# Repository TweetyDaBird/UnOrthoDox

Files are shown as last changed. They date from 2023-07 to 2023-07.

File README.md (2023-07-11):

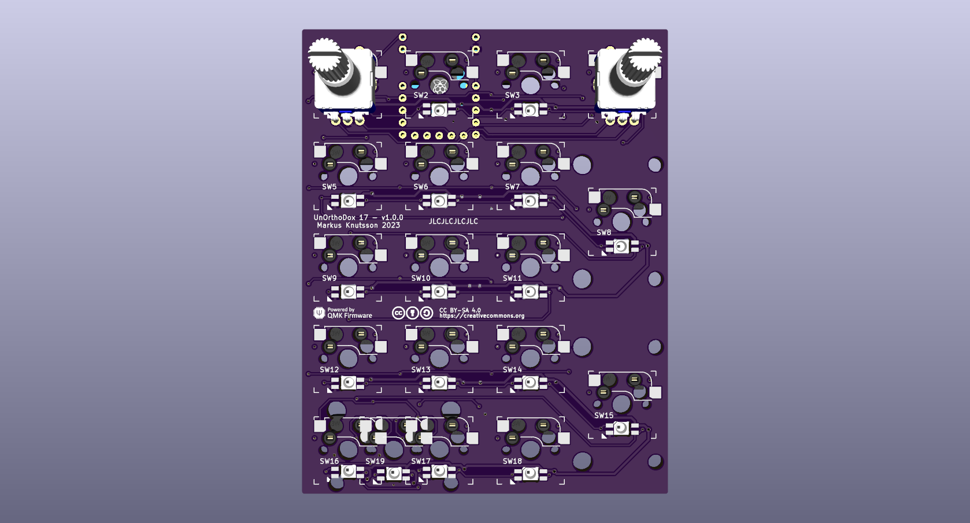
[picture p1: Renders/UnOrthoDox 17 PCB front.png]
Render UnOrthoDox 17
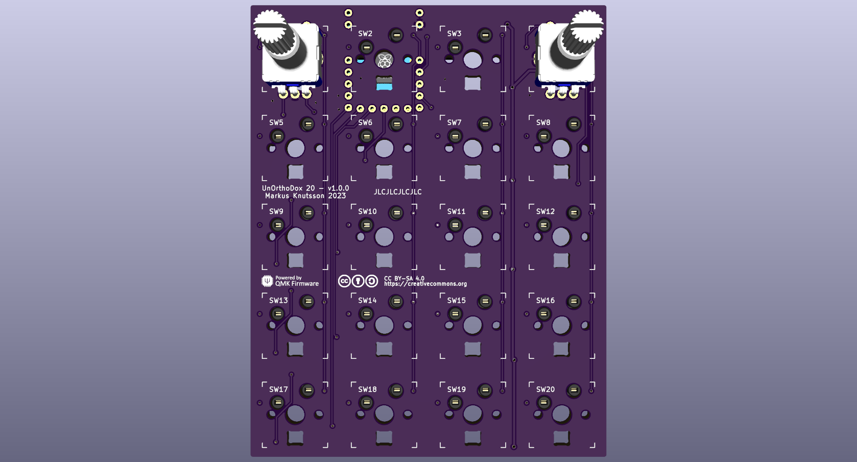
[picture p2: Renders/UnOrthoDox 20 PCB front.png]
Render UnOrthoDoc 20
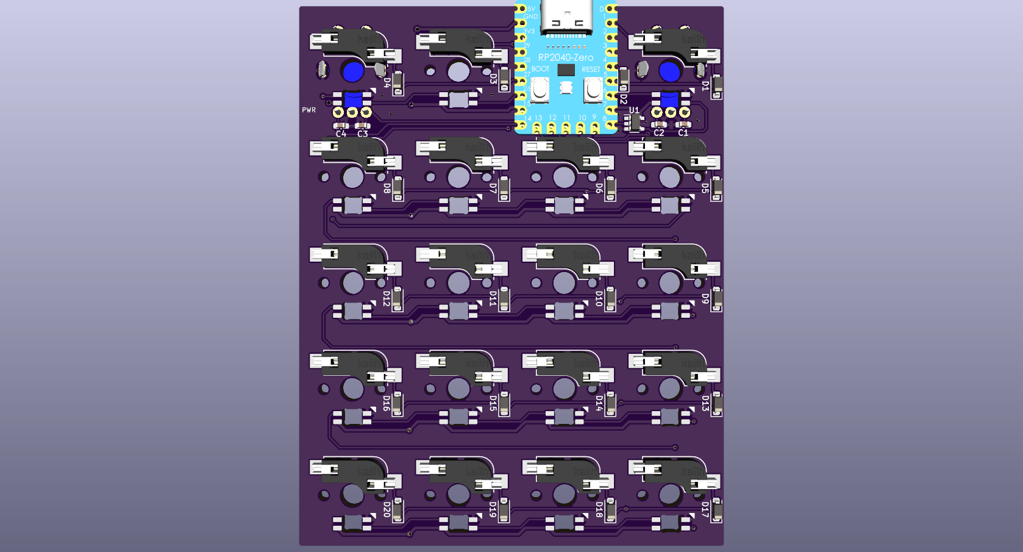
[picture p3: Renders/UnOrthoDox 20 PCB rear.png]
Render UnOrthoDoc Rear
|  |  | |
| --- | --- | --- |
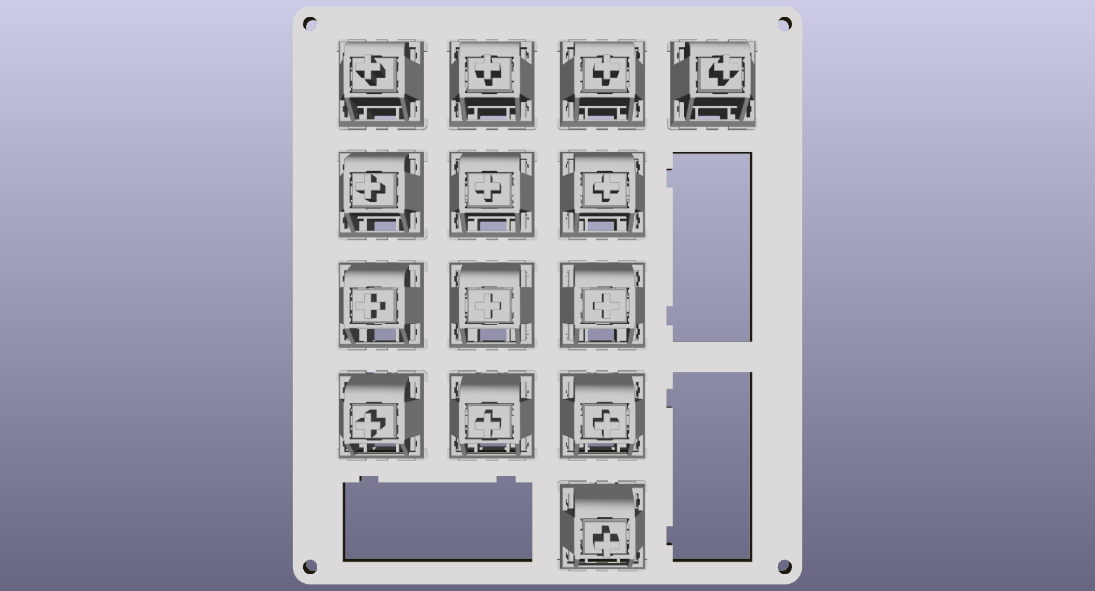
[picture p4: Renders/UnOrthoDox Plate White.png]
Render UnOrthoDox Front Plate
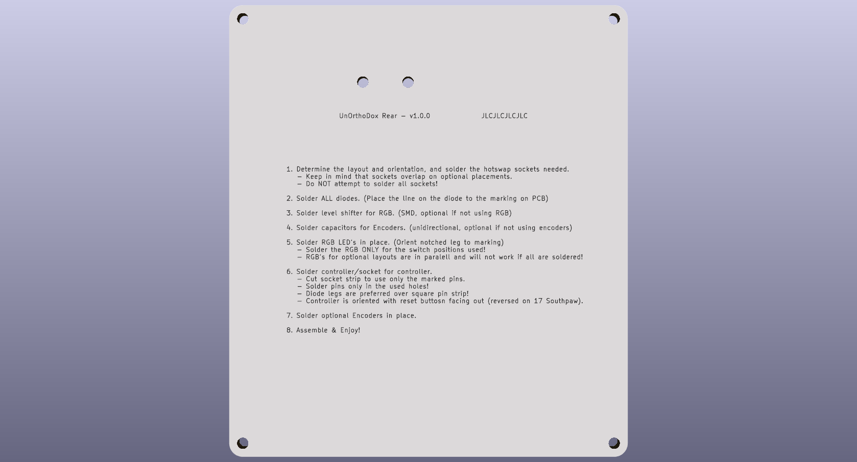
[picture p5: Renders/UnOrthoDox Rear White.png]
Render UnOrthoDox Rear Plate
| | |

# UnOrthoDox
A 'simple' and low cost hot-swap Numpad (available in 17-18 or 20 key versions) with support for dual encoders, and using a low cost but powerfull controller (RP2040-Zero). The design is dual sided, so flipping it over and building it as a 'SouthPaw' configuration is outright easy. A single plate/case design with cut-outs for all key configurations available in Black or White makes it easy to build a complete Numpad that fit's in well witha 60% keyboard in size and looks. The same plates/components fit both the 20-key PCB variant and the PCB-variant for a 17-18 key classic numpad layout. 

The name comes from the slightly unortodox placement of the controller straddling the hot-swap socket, with not all pins soldered, and the fact that it can be built as a 20-key ortholinear macro pad.

 - Full Sandwich Case design
 - Low cost/Simple to build
 - Powerful and Flexible MCU
 - Compatible with QMK/Vial and ZMK firmware
 - Reversible for SouthPaw's
 - Dual Rotary Encoders
 - Per-Key RGB
 - Build instructions are printed on the backplate for an easy build.

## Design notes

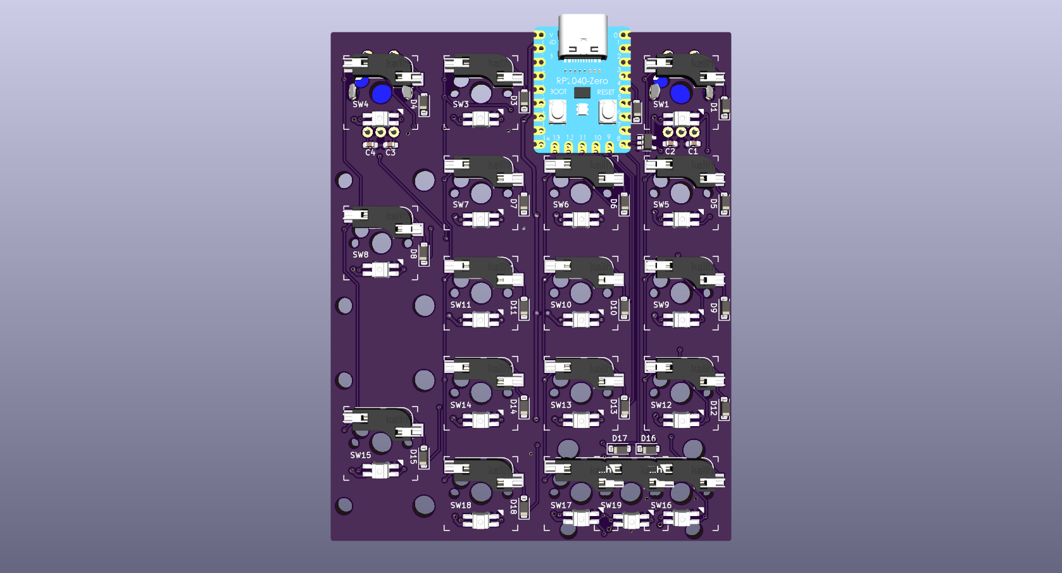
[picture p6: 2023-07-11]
Renders/UnOrthoDox 17 PCB rear.png

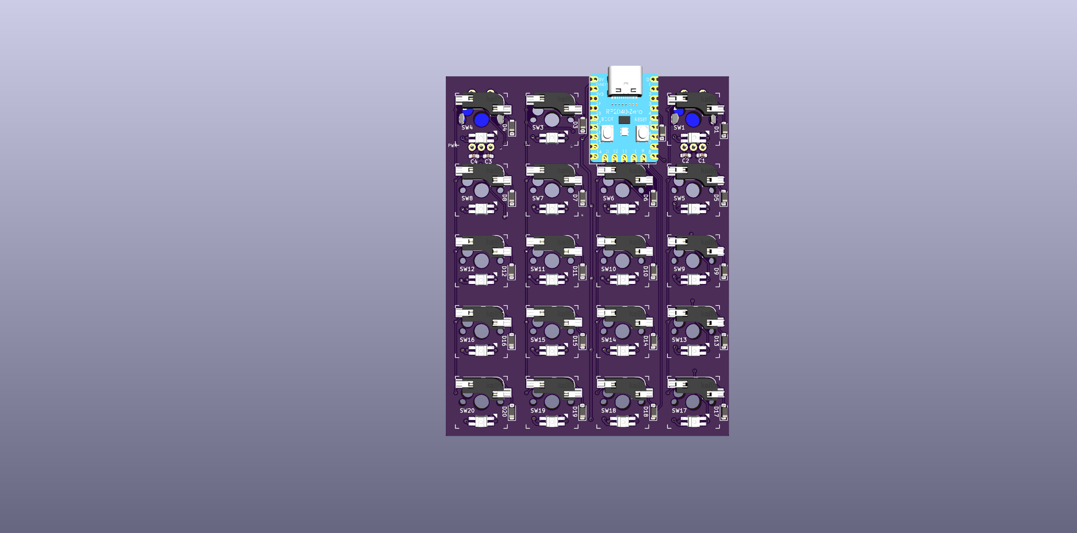
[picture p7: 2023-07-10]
UnOrthoDox 20 PCB/UnOrthoDox 20 PCB.png

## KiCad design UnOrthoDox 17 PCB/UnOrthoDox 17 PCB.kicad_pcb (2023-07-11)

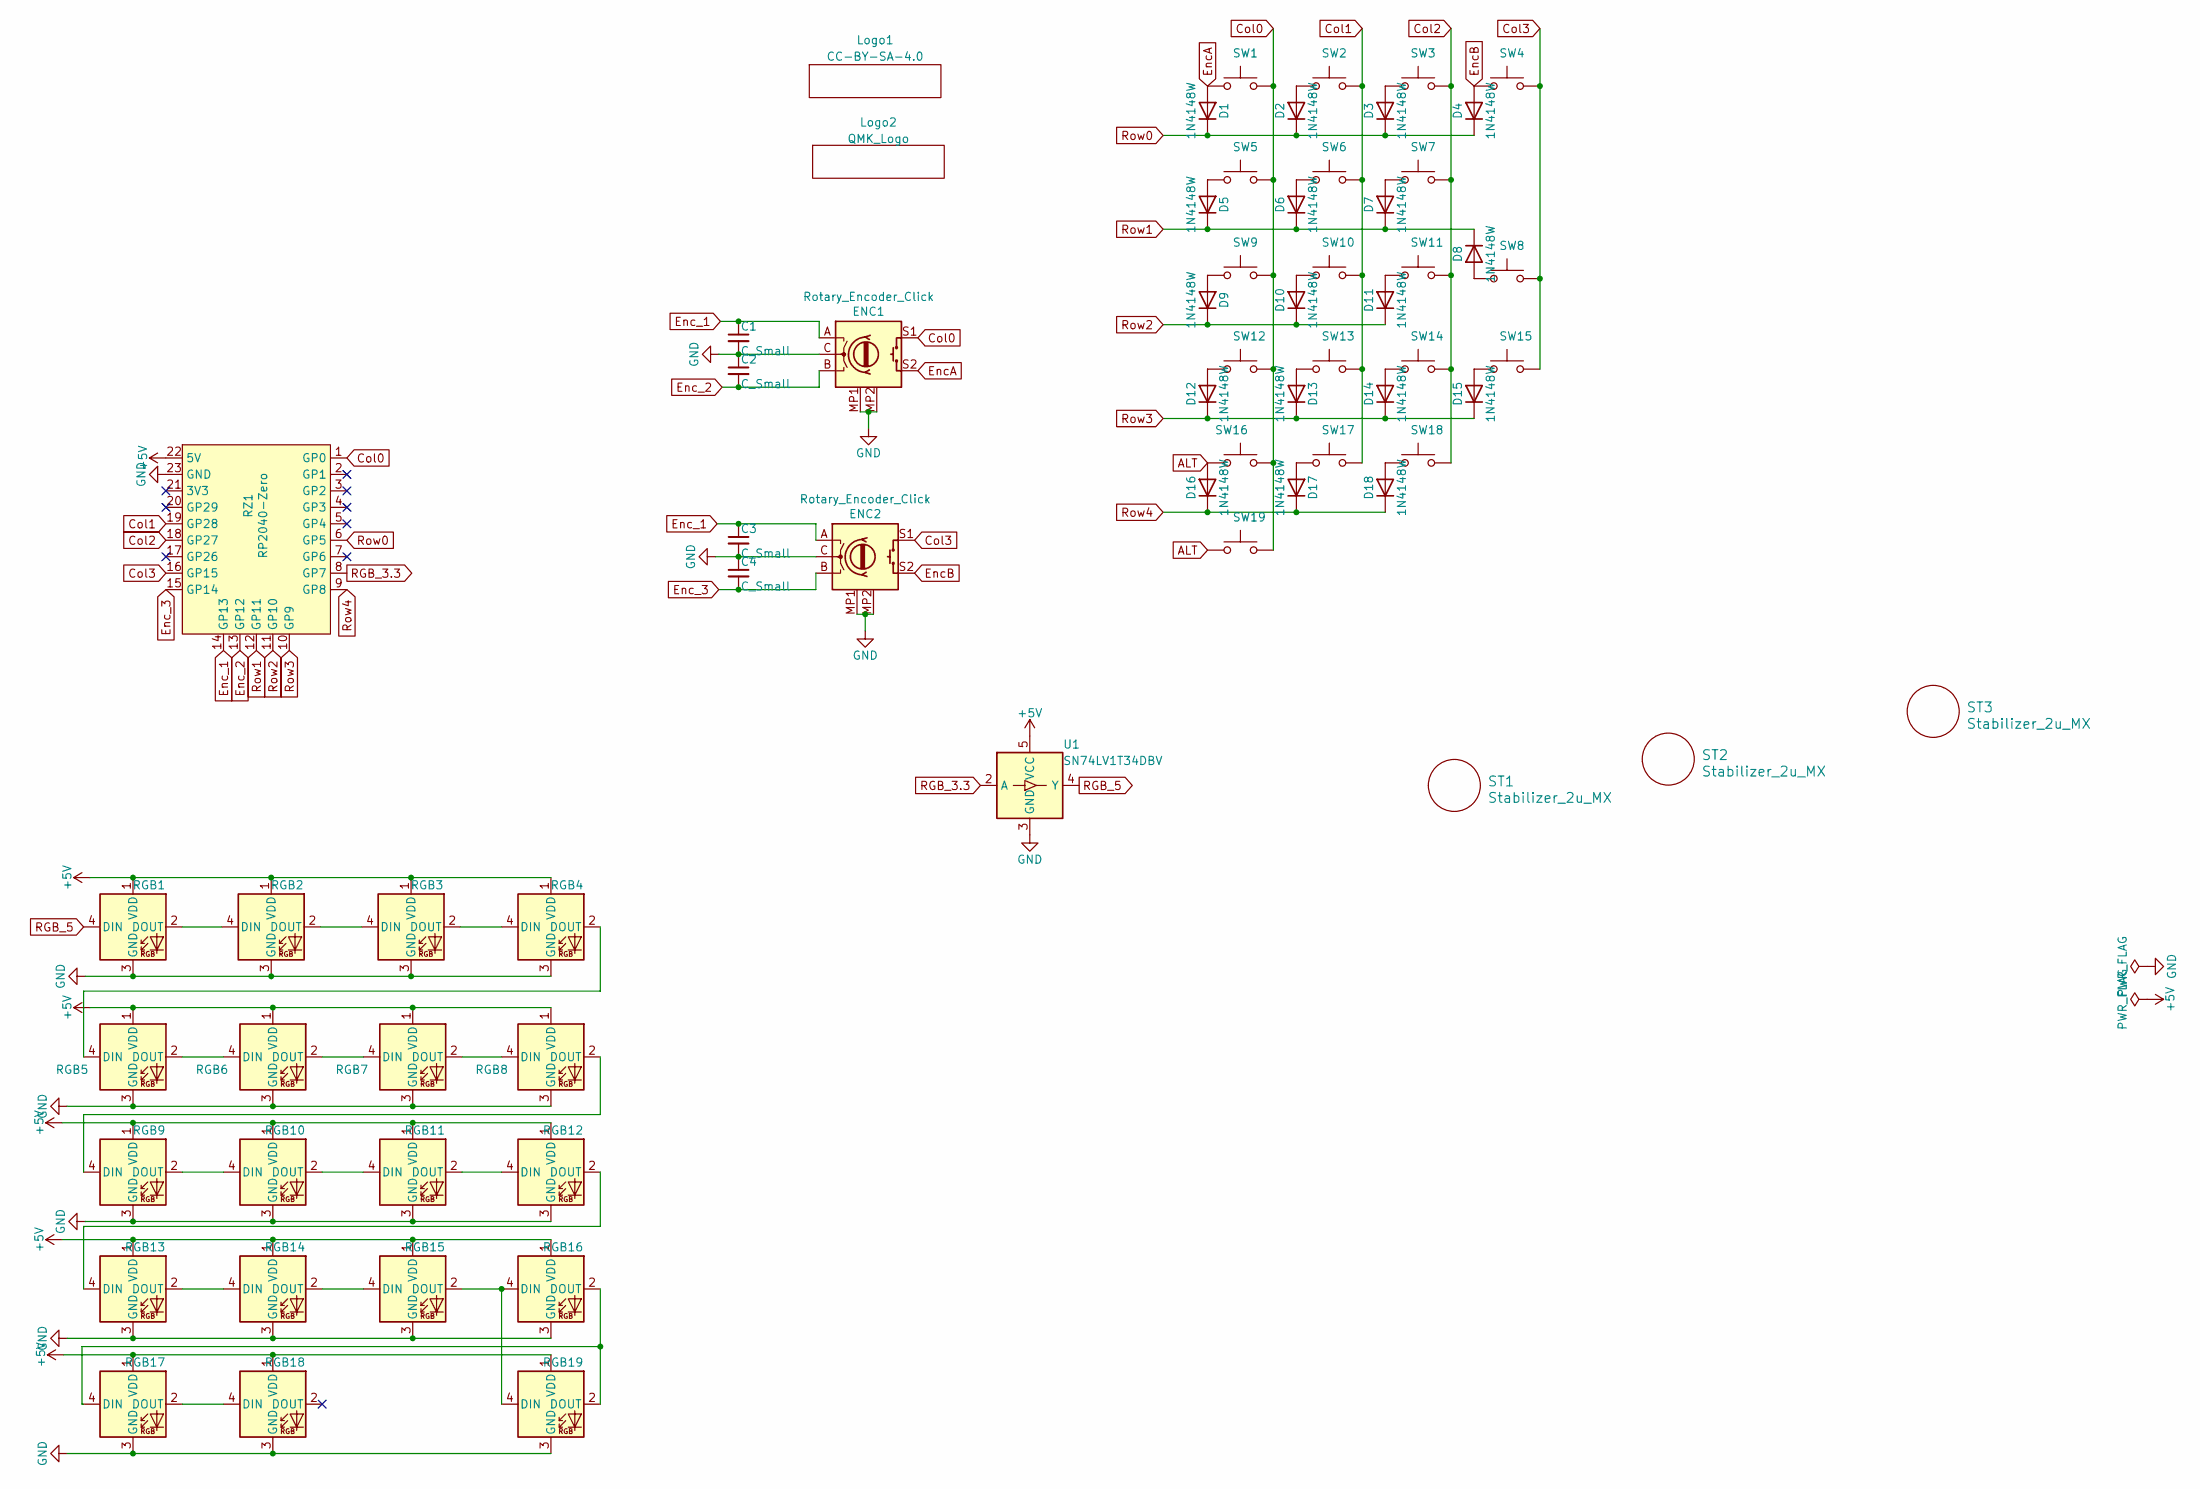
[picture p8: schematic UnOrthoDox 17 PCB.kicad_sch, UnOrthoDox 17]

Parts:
C1, C2, C3, C4: C_Small; C_0603_1608Metric_Pad1.08x0.95mm_HandSolder
D1, D2, D3, D4, D5, D6, D7, D8, D9, D10, D11, D12, D13, D14, D15, D16, D17, D18: 1N4148W; D_SOD-123
ENC1, ENC2: Rotary_Encoder_Click; Encoder_Alps_EC11E_Small
Logo1: CC-BY-SA-4.0; CC_BY_SA_40_line
Logo2: QMK_Logo; Powered_by_QMK
RGB1, RGB2, RGB3, RGB4, RGB5, RGB6, RGB7, RGB8, RGB9, RGB10, RGB11, RGB12, RGB13, RGB14, RGB15, RGB16, RGB17, RGB18, RGB19: SK6812MINI-E; MX_SK6812MINI-E_REVERSIBLE
RZ1: RP2040-Zero; RP2040-Zero_reverse_mount_flipped
ST1, ST2, ST3: Stabilizer_2u_MX; Stabilizer_Cherry_MX_2.00u
SW1, SW2, SW3, SW4, SW5, SW6, SW7, SW8, SW9, SW10, SW11, SW12, SW13, SW14, SW15, SW16, SW17, SW18, SW19: SW_MX_HotSwap; SW_MX_HotSwap_Reversible
U1: SN74LV1T34DBV; SOT-23-5

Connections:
+5V: RGB1.1 (VDD), RGB2.1 (VDD), RGB3.1 (VDD), RGB4.1 (VDD), RGB5.1 (VDD), RGB6.1 (VDD), RGB7.1 (VDD), RGB8.1 (VDD), RGB9.1 (VDD), RGB10.1 (VDD), RGB11.1 (VDD), RGB12.1 (VDD), RGB13.1 (VDD), RGB14.1 (VDD), RGB15.1 (VDD), RGB16.1 (VDD), RGB17.1 (VDD), RGB18.1 (VDD), RGB19.1 (VDD), RZ1.22 (5V), U1.5 (VCC)
ALT: D16.2 (A), SW16.2, SW19.1
Col0: ENC1.S1, RZ1.1 (GP0), SW1.2, SW5.2, SW9.2, SW12.2, SW16.1, SW19.2
Col1: RZ1.19 (GP28), SW2.2, SW6.2, SW10.2, SW13.2, SW17.2
Col2: RZ1.18 (GP27), SW3.2, SW7.2, SW11.2, SW14.2, SW18.2
Col3: ENC2.S1, RZ1.16 (GP15), SW4.2, SW8.2, SW15.2
EncA: D1.2 (A), ENC1.S2, SW1.1
EncB: D4.2 (A), ENC2.S2, SW4.1
Enc_1: C1.1, C3.1, ENC1.A, ENC2.A, RZ1.14 (GP13)
Enc_2: C2.2, ENC1.B, RZ1.13 (GP12)
Enc_3: C4.2, ENC2.B, RZ1.15 (GP14)
GND: C1.2, C2.1, C3.2, C4.1, ENC1.C, ENC1.MP1 (GND), ENC1.MP2 (GND), ENC2.C, ENC2.MP1 (GND), ENC2.MP2 (GND), RGB1.3 (GND), RGB2.3 (GND), RGB3.3 (GND), RGB4.3 (GND), RGB5.3 (GND), RGB6.3 (GND), RGB7.3 (GND), RGB8.3 (GND), RGB9.3 (GND), RGB10.3 (GND), RGB11.3 (GND), RGB12.3 (GND), RGB13.3 (GND), RGB14.3 (GND), RGB15.3 (GND), RGB16.3 (GND), RGB17.3 (GND), RGB18.3 (GND), RGB19.3 (GND), RZ1.23 (GND), U1.3 (GND)
unnamed: D2.2 (A), SW2.1
unnamed: D3.2 (A), SW3.1
unnamed: D5.2 (A), SW5.1
unnamed: D6.2 (A), SW6.1
unnamed: D7.2 (A), SW7.1
unnamed: D8.2 (A), SW8.1
unnamed: D9.2 (A), SW9.1
unnamed: D10.2 (A), SW10.1
unnamed: D11.2 (A), SW11.1
unnamed: D12.2 (A), SW12.1
unnamed: D13.2 (A), SW13.1
unnamed: D14.2 (A), SW14.1
unnamed: D15.2 (A), SW15.1
unnamed: D17.2 (A), SW17.1
unnamed: D18.2 (A), SW18.1
unnamed: RGB1.2 (DOUT), RGB2.4 (DIN)
unnamed: RGB2.2 (DOUT), RGB3.4 (DIN)
unnamed: RGB3.2 (DOUT), RGB4.4 (DIN)
unnamed: RGB4.2 (DOUT), RGB5.4 (DIN)
unnamed: RGB5.2 (DOUT), RGB6.4 (DIN)
unnamed: RGB6.2 (DOUT), RGB7.4 (DIN)
unnamed: RGB7.2 (DOUT), RGB8.4 (DIN)
unnamed: RGB8.2 (DOUT), RGB9.4 (DIN)
unnamed: RGB9.2 (DOUT), RGB10.4 (DIN)
unnamed: RGB10.2 (DOUT), RGB11.4 (DIN)
unnamed: RGB11.2 (DOUT), RGB12.4 (DIN)
unnamed: RGB12.2 (DOUT), RGB13.4 (DIN)
unnamed: RGB13.2 (DOUT), RGB14.4 (DIN)
unnamed: RGB14.2 (DOUT), RGB15.4 (DIN)
unnamed: RGB15.2 (DOUT), RGB16.4 (DIN), RGB19.4 (DIN)
unnamed: RGB16.2 (DOUT), RGB17.4 (DIN), RGB19.2 (DOUT)
unnamed: RGB17.2 (DOUT), RGB18.4 (DIN)
RGB_3.3: RZ1.8 (GP7), U1.2 (A)
RGB_5: RGB1.4 (DIN), U1.4 (Y)
Row0: D1.1 (K), D2.1 (K), D3.1 (K), D4.1 (K), RZ1.6 (GP5)
Row1: D5.1 (K), D6.1 (K), D7.1 (K), D8.1 (K), RZ1.12 (GP11)
Row2: D9.1 (K), D10.1 (K), D11.1 (K), RZ1.11 (GP10)
Row3: D12.1 (K), D13.1 (K), D14.1 (K), D15.1 (K), RZ1.10 (GP9)
Row4: D16.1 (K), D17.1 (K), D18.1 (K), RZ1.9 (GP8)

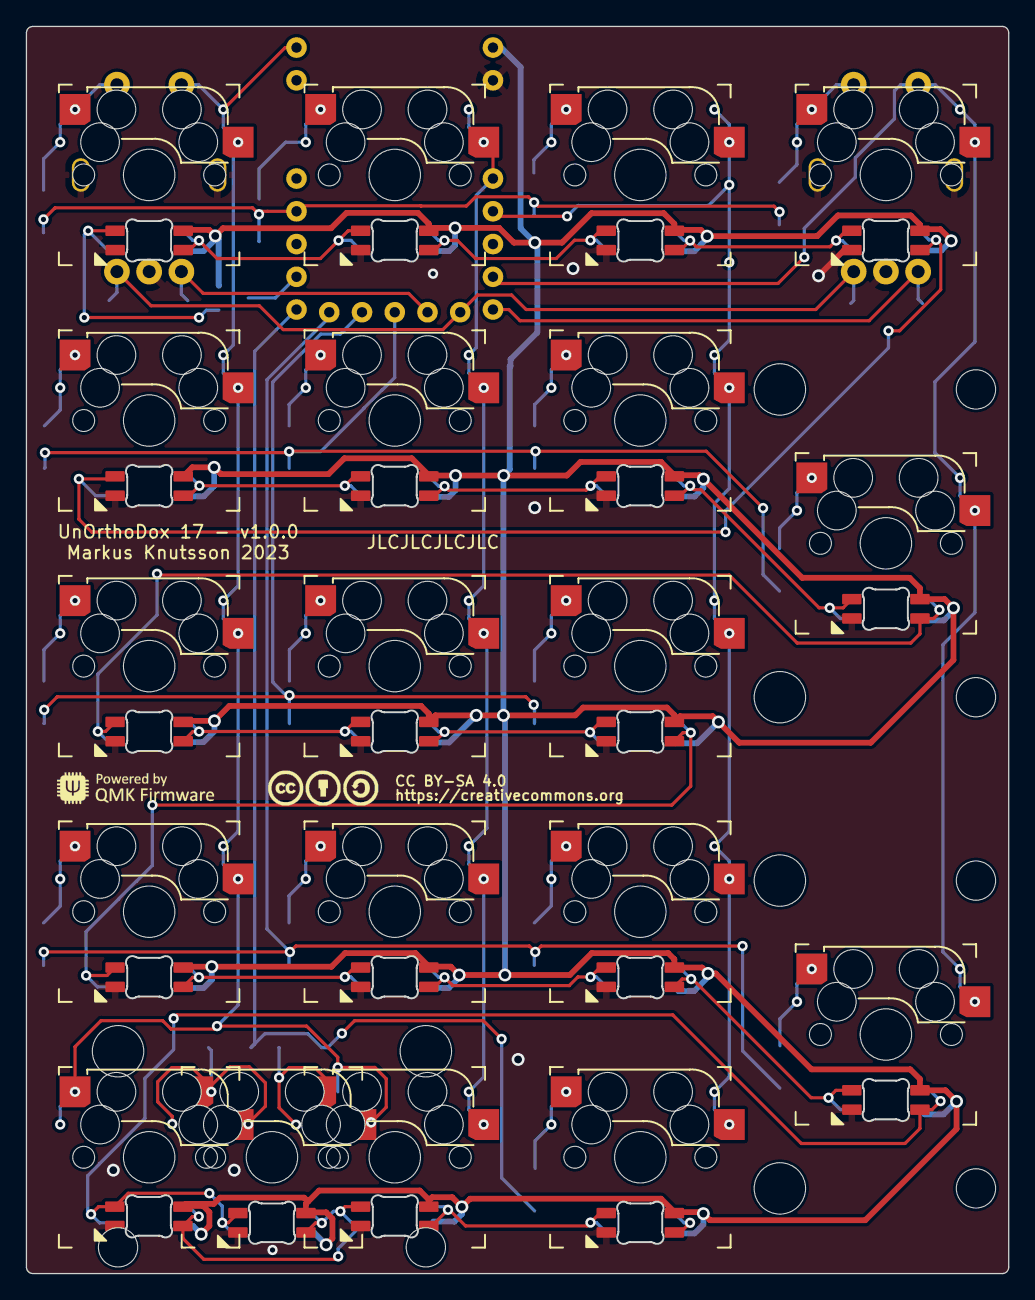
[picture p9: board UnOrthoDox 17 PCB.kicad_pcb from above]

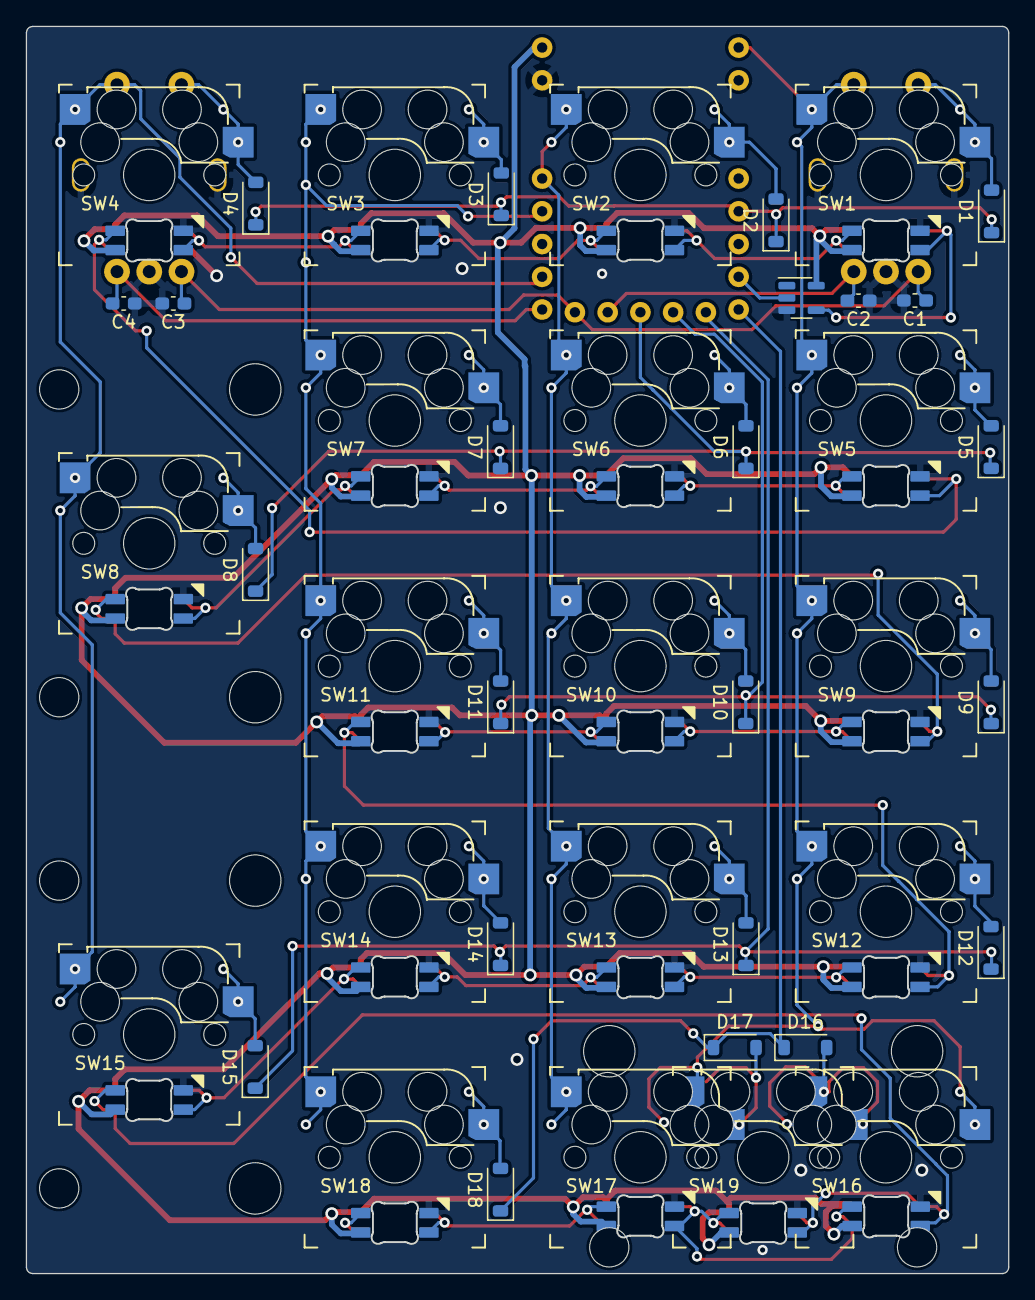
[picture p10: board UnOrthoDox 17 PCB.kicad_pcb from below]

Board: 2 copper layers, 76.2 x 96.7 mm, 69 parts (24 on the bottom side), 51 nets.

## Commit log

2023-04-23 First version
    [UnOrthoDox 20 PCB.kicad_pcb, UnOrthoDox 20 PCB.kicad_sch, UnOrthoDox 20 Plate.kicad_pcb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]
2023-07-10 Added 17
    [UnOrthoDox 17 PCB.kicad_pcb, UnOrthoDox 17 PCB.kicad_sch, UnOrthoDox 20 PCB.kicad_pcb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]
2023-07-11 Final tweaks 17/20 PCB
    [UnOrthoDox 17 PCB.kicad_pcb, UnOrthoDox 17 PCB.kicad_sch, UnOrthoDox 20 PCB.kicad_pcb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]
2023-07-11 Reworked plates for release
    [UnOrthoDox 20 Plate.kicad_pcb, UnOrthoDox 20 Plate.kicad_sch, UnOrthoDox 20 Rear.kicad_sch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]
2023-07-11 Updated renders
    [UnOrthoDox 17 PCB.kicad_pcb, UnOrthoDox Rear.kicad_pcb]

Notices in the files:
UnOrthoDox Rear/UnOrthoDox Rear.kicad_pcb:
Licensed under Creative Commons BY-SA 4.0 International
